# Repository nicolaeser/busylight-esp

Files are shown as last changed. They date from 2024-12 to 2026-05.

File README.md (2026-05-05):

# NOTICE: REPOSITORY IS NOW ARCHIVED
# CODE IS HOSTED @ http://code.igox.org/iGoX/busylight

# Table of Content

1. [What's this project?](#whats-this-project)
2. [Web UI](#web-ui)
3. [Stream Deck plug-in](#stream-deck-plug-in)
4. [BusyLight API](#busylight-api)
5. [MuteDeck integration](#mutedeck-integration)
6. [Electronic parts](#electronic-parts)
7. [Firmware installation](#firmware-installation)
8. [3D files - Enclosure](#3d-files---enclosure)
9. [Wiring / Soldering](#wiring--soldering)
10. [Tools & libs](#tools--libs)

# What's this project?

**Let people know if they can bother you with light signals!**

A cheap, simple to build, nice looking and portable DIY **Busy Light**.

It comes with a with a simplistic but neat **Web UI** and a simple (but hopefully convenient) **Rest API**.

| Controlled by Stream Deck with REST API | Light roll | 
|---|---|
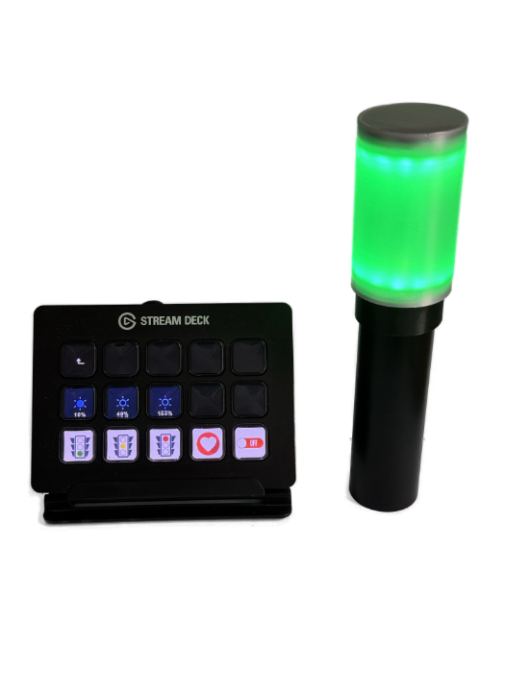
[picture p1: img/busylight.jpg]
busylight and stream deck
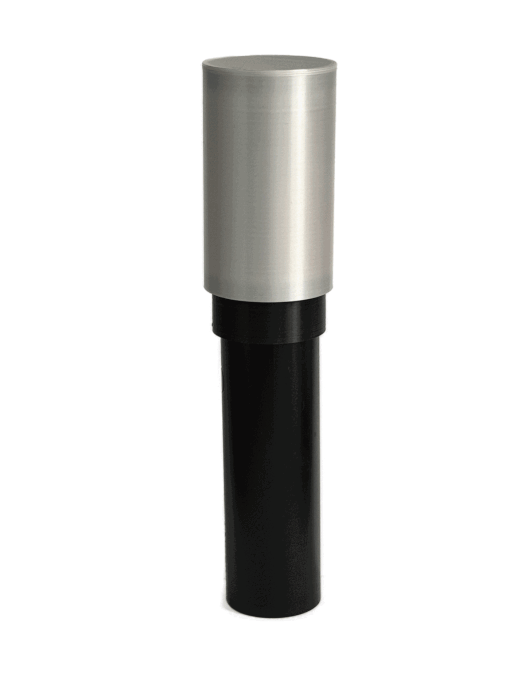
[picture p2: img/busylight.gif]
busylight roll
|  |   |

showoff video

# Web UI
A very simplistic but neat UI is available on port `80` (thanks @nicolaeser). \
Default hostname is `igox-busylight`.

You can try to reach the web UI @ [http://igox-busylight.local](http://igox-busylight.local). 

| What an neat UI ! :smile: |
|---------------------------|
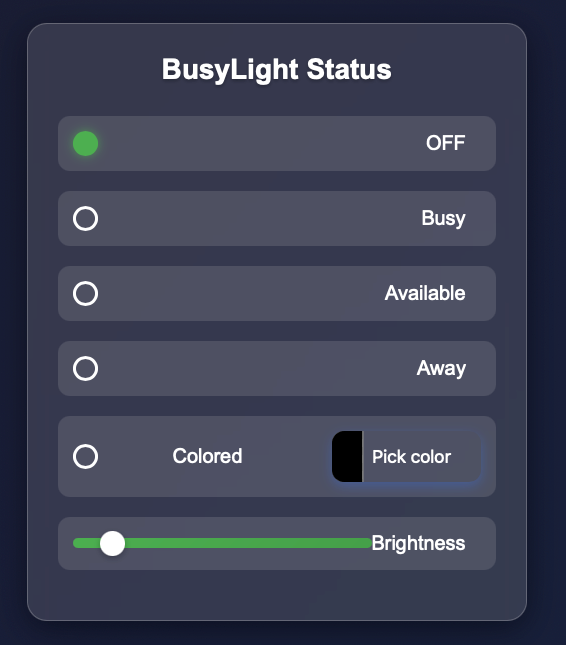
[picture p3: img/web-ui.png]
Web UI
|  |

# Stream Deck plug-in
You can download a Stream Deck plugin to control your BusyLight:

get it on marketplace Get iGoX BusyLight on Marketplace (https://marketplace.elgato.com/product/igox-busylight-7448a0be-6dd6-4711-ba0d-86c52b9075b9)

Or directly from [here](streamdeck-plugin/README.md).

# BusyLight API
## End points
| Path | Method | Parameter | Description |
|---|---|---|---|
| /api/color | POST | `color` JSON object | Set the BusyLight color according to the `color` object passed in the request body. Return a `status` object. |
| /api/color |  GET | n/a | Retreive the color currently displyed by the BusyLight. Return a `color` object. |
| /api/brightness | POST | `brightness` JSON object | Set the BusyLight brightness according to the `brightness` object passed in the request body. Return a `status` object. |
| /api/brightness | GET | n/a | Retreive the BusyLight brightness. Return a `brightness` object. |
| /api/status/on | POST / GET | n/a | Light up the BusyLight. White color. Return a `status` object. |
| /api/status/available | POST / GET | n/a | Set the BusyLight in `available` mode. Green color. Return a `status` object. |
| /api/status/away | POST / GET | n/a | Set the BusyLight in `away` mode. Yellow color. Return a `status` object. |
| /api/status/busy | POST / GET | n/a | Set the BusyLight in `busy` mode. Red color. Return a `status` object. |
| /api/status/off | POST / GET | n/a | Shutdown the BusyLight. Return a `status` object. |
| /api/status |  GET | n/a | Retreive the current BusyLight status. Return a `status` object. |
| /api/debug |  GET | n/a | Retreive the full BusyLight status. |

## JSON objects
### `color` object

```
{
  "r": 255,
  "g": 0,
  "b": 127,
  "brightness": 0.5
}
```
`r`: RED color | integer | [0 .. 255]\
`g`: GREEN color | integer | [0 .. 255]\
`b`: BLUE color | integer | [0 .. 255]\
`brightness`: LED brighness (optional)  | float | [0.0 .. 1.0]

### `brightness` object

```
{
  "brightness": 0.5
}
```
`brightness`: LED brighness | float | [0.0 .. 1.0]

### `status` object

```
{
  "status": "<STATUS>"
}
```

\<STATUS\> : `on` | `off` | `available` | `away` | `busy` | `colored`

# MuteDeck integration
The `POST api/mutedeck-webhook` endpoint aims to collect [MuteDeck](https://mutedeck.com/help/docs/notifications.html#enabling-the-webhook-integration) webhook callbacks.

It will automatically switch to the BusyLight in:
- busy mode (Red color) when entering a meeting with Mic `ON` **and** camera `ON`.
- away mode (Yellow color) when entering a meeting with Mic `OFF` **and** camera `ON`.
- away mode (Yellow color) if the mic is muted during a meeting.
- available mode (Green color) when exiting/closing a meeting.

| MuteDeck Configuration                            |
|---------------------------------------------------|
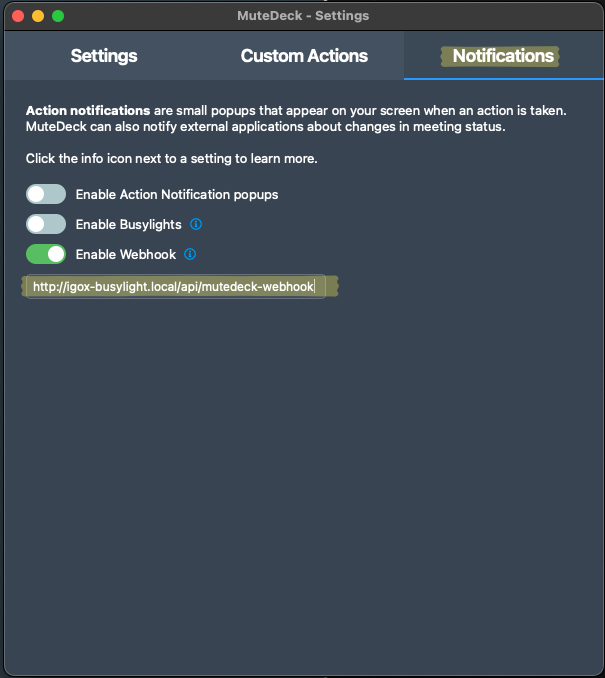
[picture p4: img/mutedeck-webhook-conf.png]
MuteDeck config
|  |

# Electronic parts
| Parts | Links (Amazon - not affiliated) |
|---|---|
| Micro-controler | [D1 ESP32 Mini NodeMCU](https://www.amazon.fr/dp/B0CDXB48DZ) - USB C version |
| Led rings (x2) | [AZDelivery 5 x LED Ring 5V RGB compatible avec WS2812B 12-Bit 38mm](https://www.amazon.fr/dp/B07V1GGKHV) |
| Battery | [Anker PowerCore 5000mAh](https://www.amazon.fr/dp/B01CU1EC6Y) |
| USB A to USB C adapter  | [USB A to USB C adapter](https://www.amazon.fr/dp/B0BYK917NM) |

# Firmware installation

**(1)** Flash your ESP32 with [Micropython](https://micropython.org/download/ESP32_GENERIC/).

**(2)** Install [microdot](https://microdot.readthedocs.io/en/latest/index.html) library on the ESP32. This can easily be done using [Thonny](https://thonny.org):

| Tools > Manage plug-ins | lib selection |
|---|---|
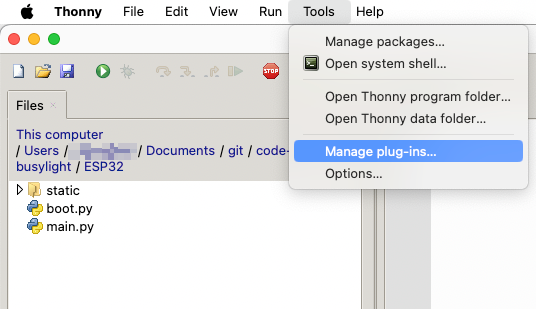
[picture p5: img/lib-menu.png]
lib-menu
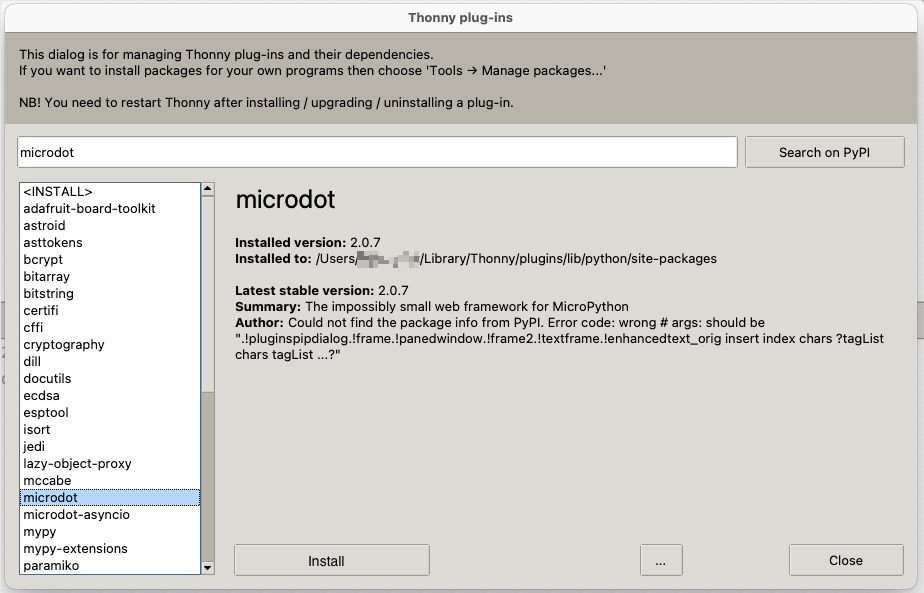
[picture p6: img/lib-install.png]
lib-install
|  |  |

**(3)** Edit the `WIFI Configuration` section in the [boot.py](ESP32/boot.py) file.

**(4)** Copy the content of [ESP32](ESP32/) folder with the modified `boot.py` file to the root of your ESP32 file system. Again, can easily be done using [Thonny](https://thonny.org):

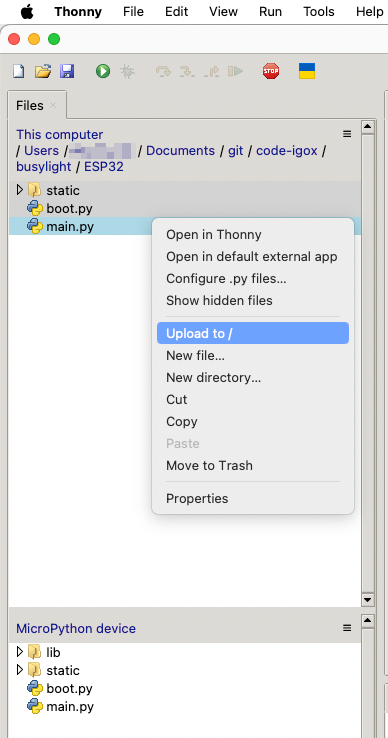
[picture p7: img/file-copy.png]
file-copy


**Done!**

# 3D files - Enclosure

All the required 3D files (STLs and f3d project) to 3D print the enclosure are available in the [3D-files-to-print](3D-files-to-print/) folder.

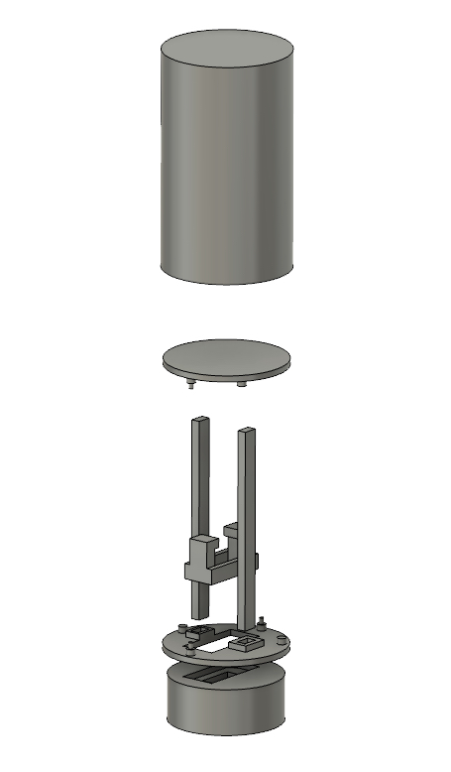
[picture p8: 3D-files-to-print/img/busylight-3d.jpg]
3D files


# Wiring / Soldering

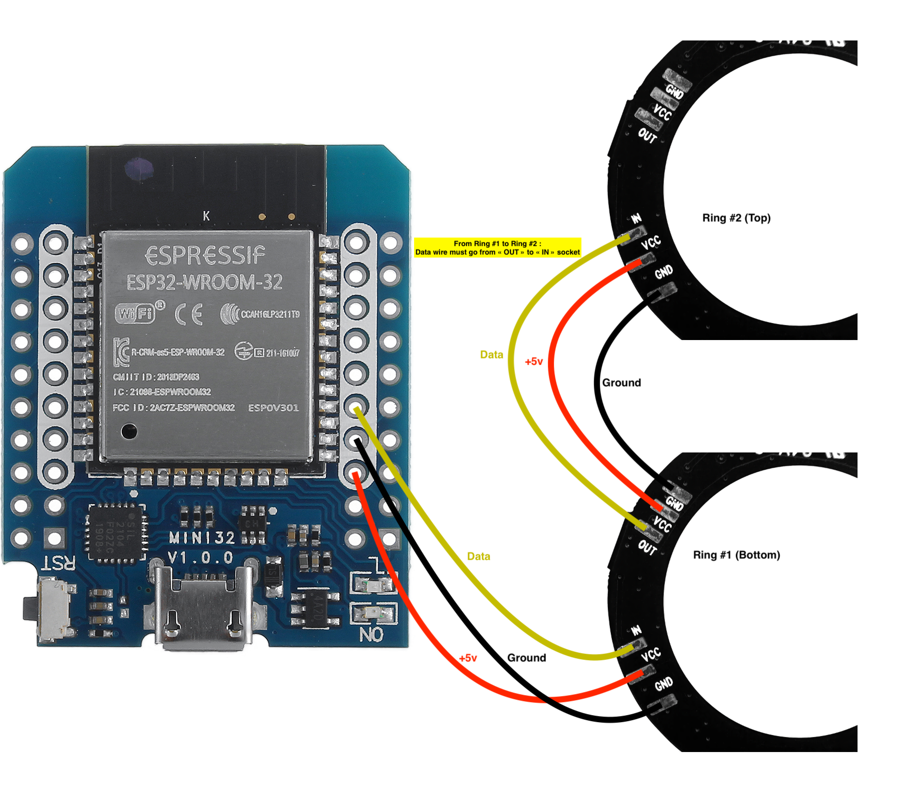
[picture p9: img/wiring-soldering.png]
wiring-soldering


You can see a final assembly image [here](3D-files-to-print/README.md).

# Tools & libs

## Thonny
https://thonny.org

## Micropython
https://micropython.org

## Microdot
https://microdot.readthedocs.io/en/latest/index.html

## JSColor
https://jscolor.com

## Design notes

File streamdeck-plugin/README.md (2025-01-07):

# BusyLight Stream Deck plugin - Release notes

## Version 0.3.1.0 (2024-01-06)

### Download

[org.igox.busylight.v0.3.1.0.streamDeckPlugin](download/org.igox.busylight.v0.3.1.0.streamDeckPlugin)

### Features

- None added

### Enhancements

- Add colored button for "Set color" action.
- Add colored button for "Set brightness" action.
- Update plugin and plugin category icons

### Fixes

- None.

### Bugs & known limitations

- None known at publication time.

### Screenshot

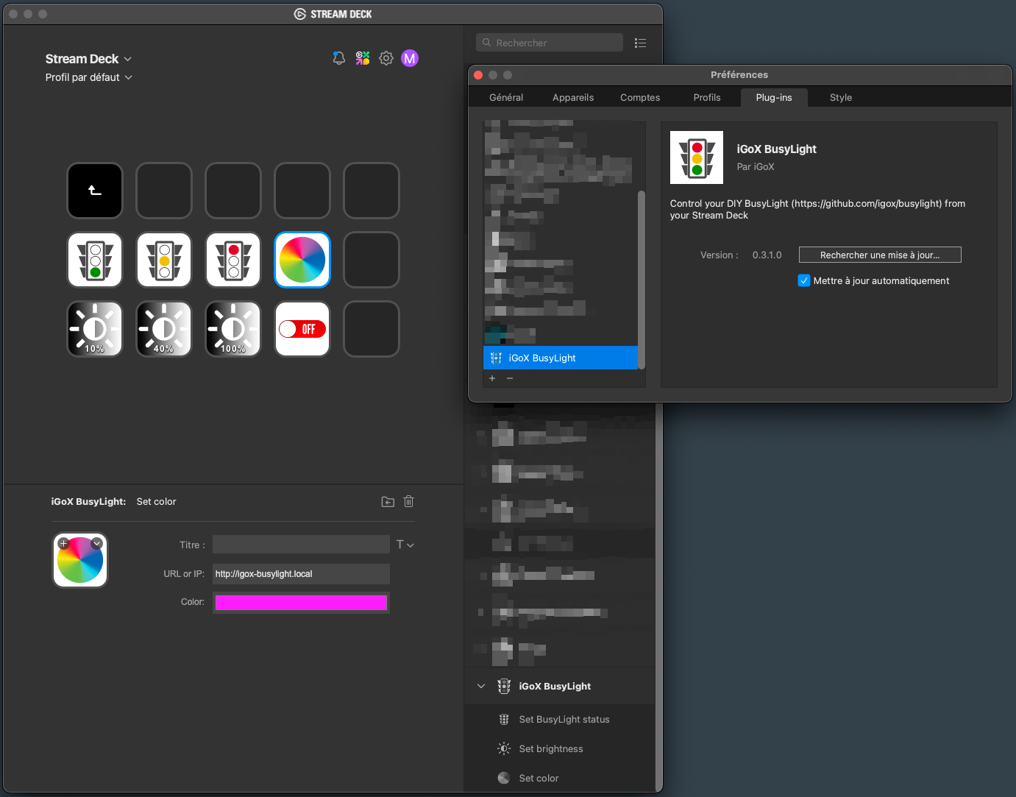
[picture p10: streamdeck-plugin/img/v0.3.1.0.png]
v0.3.1.0 screenshot


## Version 0.3.0.0 (2024-01-06)

### Download

[org.igox.busylight.v0.3.0.0.streamDeckPlugin](download/org.igox.busylight.v0.3.0.0.streamDeckPlugin)

### Features

- None added

### Enhancements

- Rework icons to comply with plugin guidelines for Elgato Marketplace
- Combine the 3 "status" actions into a single action and having the status be selected with a dropdown

### Fixes

- None.

### Bugs & known limitations

- None known at publication time.

### Screenshot

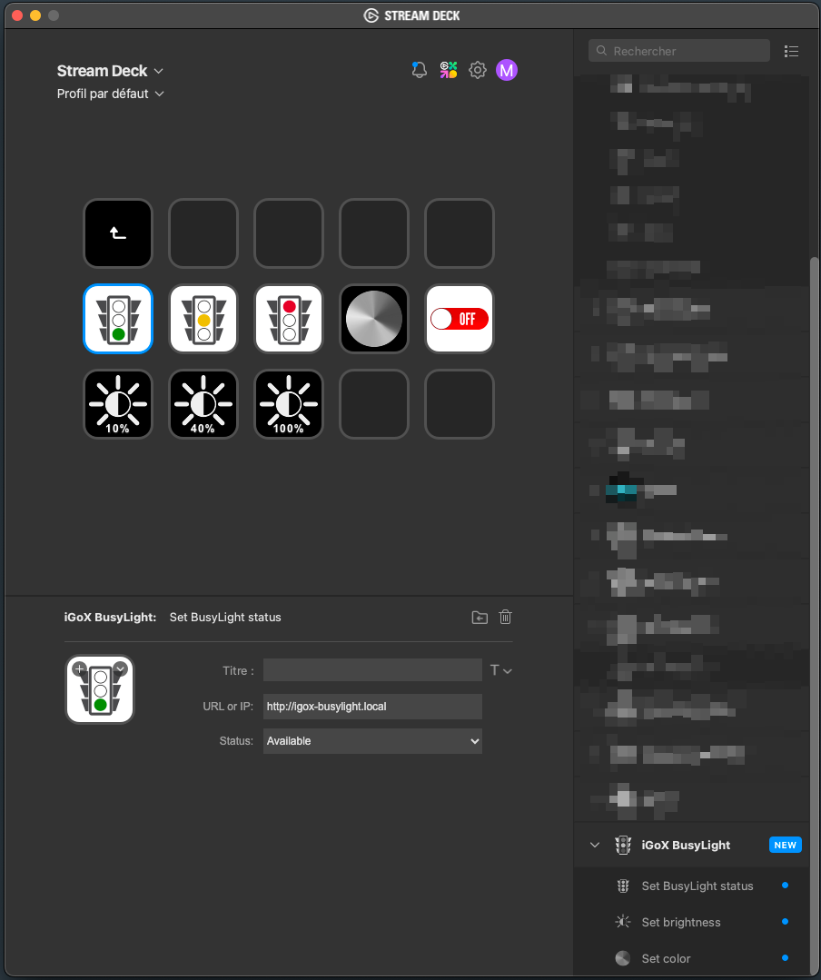
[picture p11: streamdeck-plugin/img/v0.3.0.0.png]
v0.3.0.0 screenshot


## Version 0.2.0.0 (2024-12-28)

### Download

[org.igox.busylight.v0.2.0.0.streamDeckPlugin](download/org.igox.busylight.v0.2.0.0.streamDeckPlugin)

### Features

- Add the capability to set the color diplayed by BusyLigh LEDs.

### Fixes

- None.

### Bugs & known limitations

- None known at publication time.

### Screenshot

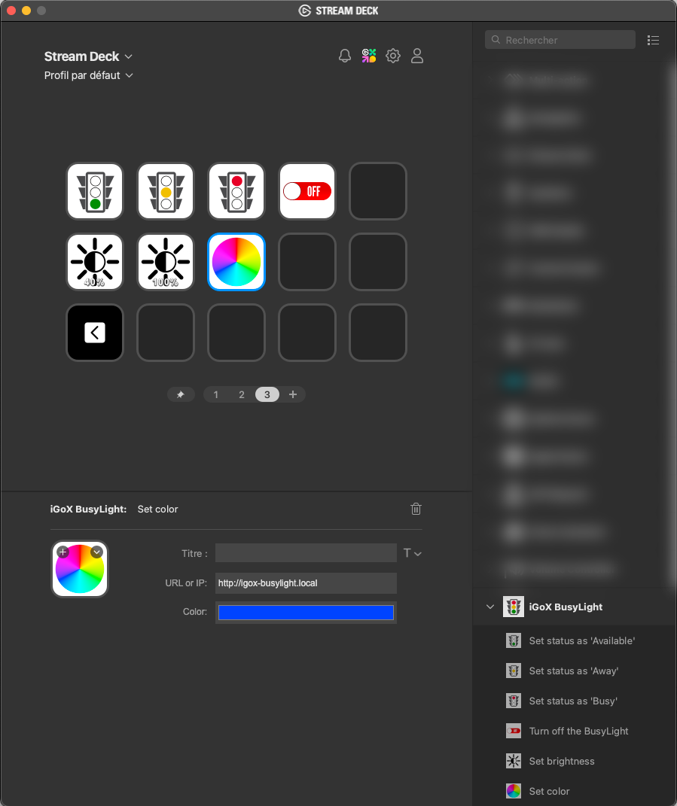
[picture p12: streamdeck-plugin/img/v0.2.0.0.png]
v0.2.0.0 screenshot


## Version 0.1.0.0 (2024-12-28)

### Download

[org.igox.busylight.v0.1.0.0.streamDeckPlugin](download/org.igox.busylight.v0.1.0.0.streamDeckPlugin)

### Features

- Quick action buttons to set the BusyLight status (Available: green, Away: yellow, Busy: red).
- Quick action button to turn off the BusyLight.
- Button to set the BusyLight brightness.

### Fixes

- None: initial version of the plugin.

### Bugs & known limitations

- None known at publication time.

### Screenshot

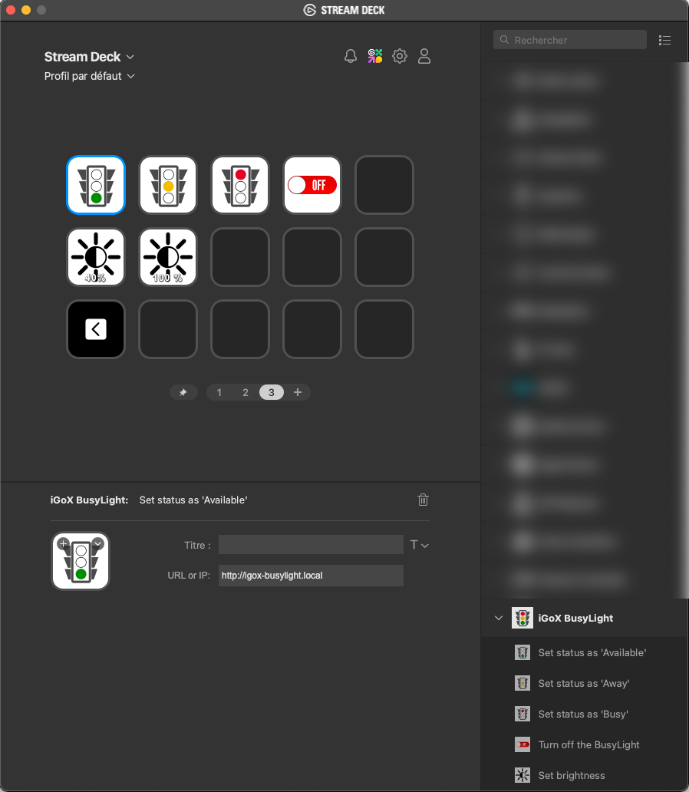
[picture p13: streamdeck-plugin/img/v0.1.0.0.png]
v0.1.0.0 screenshot


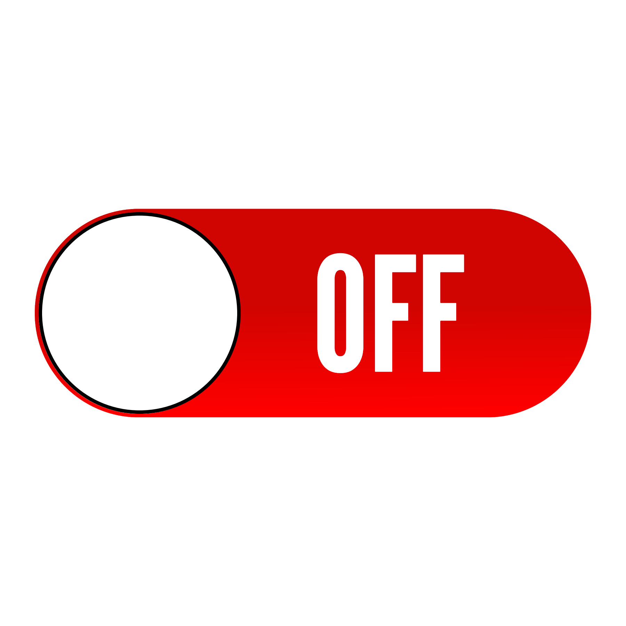
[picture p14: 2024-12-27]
streamdeck-plugin/busylight/org.igox.busylight.sdPlugin/imgs/actions/buttons/off/off@2x.png

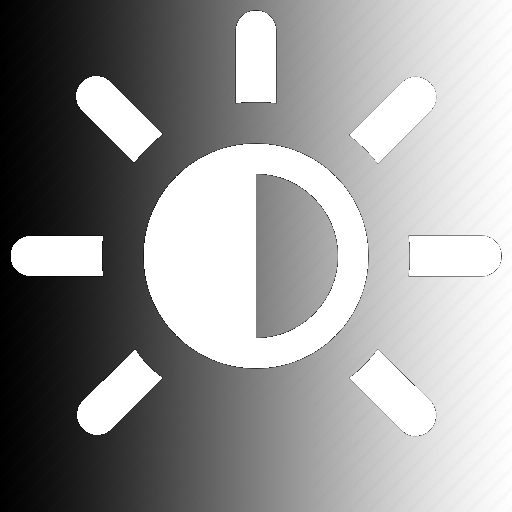
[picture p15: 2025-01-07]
streamdeck-plugin/busylight/org.igox.busylight.sdPlugin/imgs/actions/buttons/brigthness/brigthness@2x.png

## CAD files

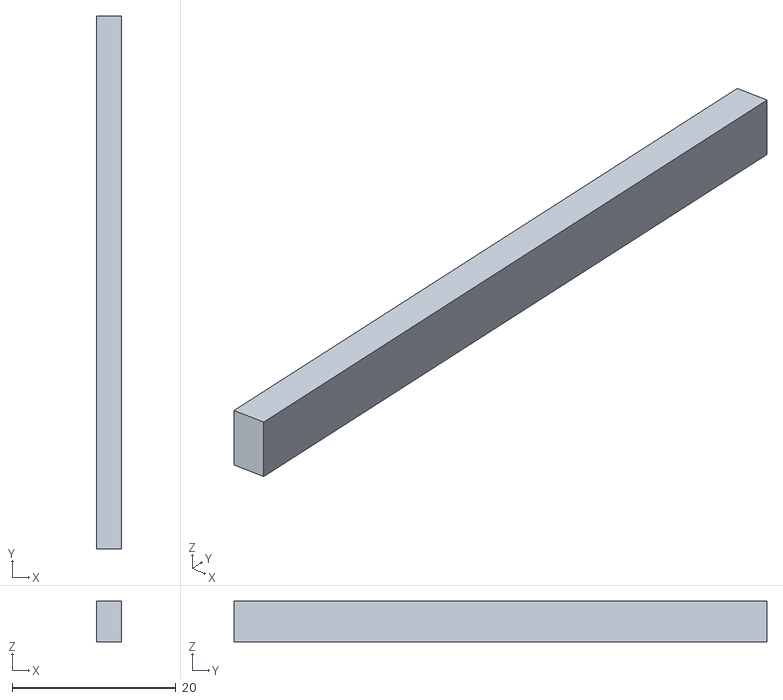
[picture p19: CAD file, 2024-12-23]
3D-files-to-print/Raiser.stl
3.00 x 65.0 x 5.00

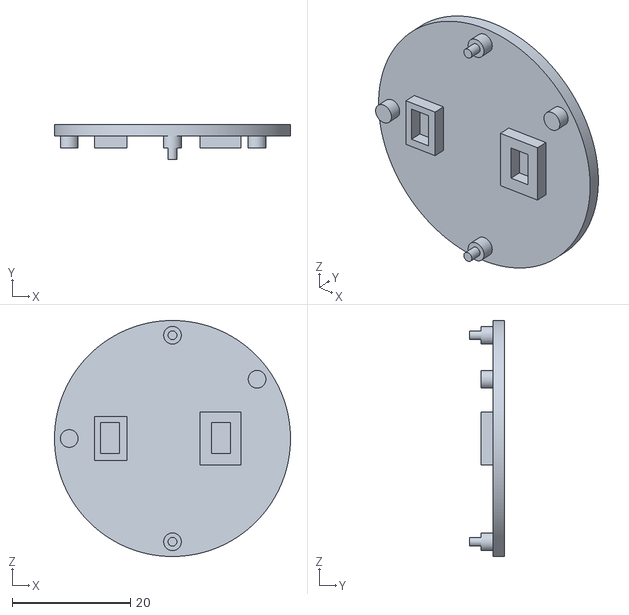
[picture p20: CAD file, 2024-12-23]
3D-files-to-print/LED support top.stl
40.0 x 6.00 x 40.0

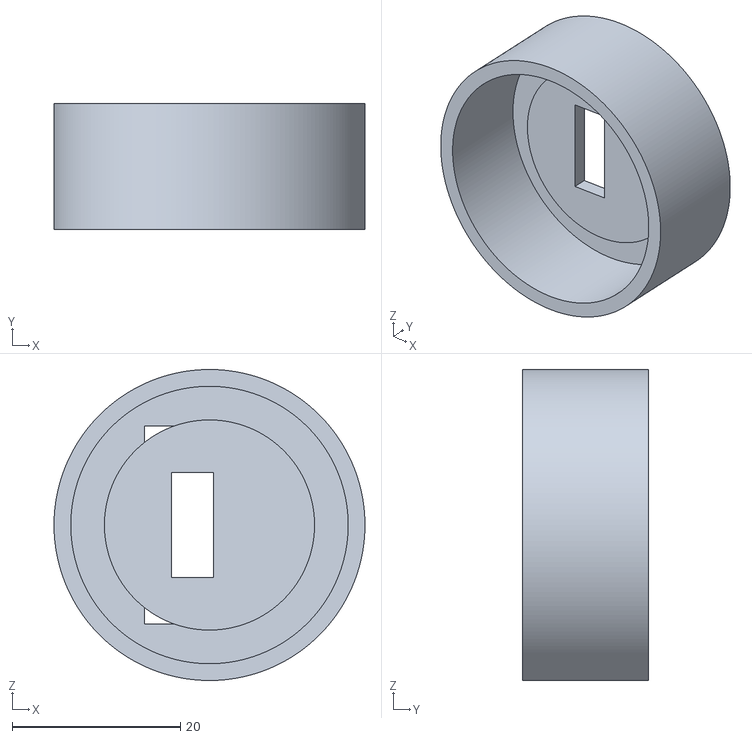
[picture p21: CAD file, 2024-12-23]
3D-files-to-print/USB plate.stl
37.0 x 15.0 x 37.0

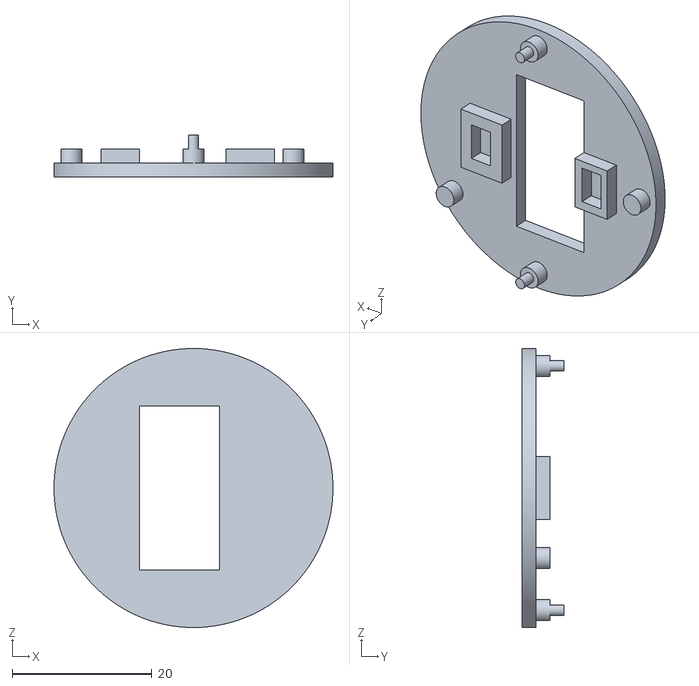
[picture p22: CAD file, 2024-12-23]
3D-files-to-print/LED support bottom.stl
40.0 x 6.00 x 40.0

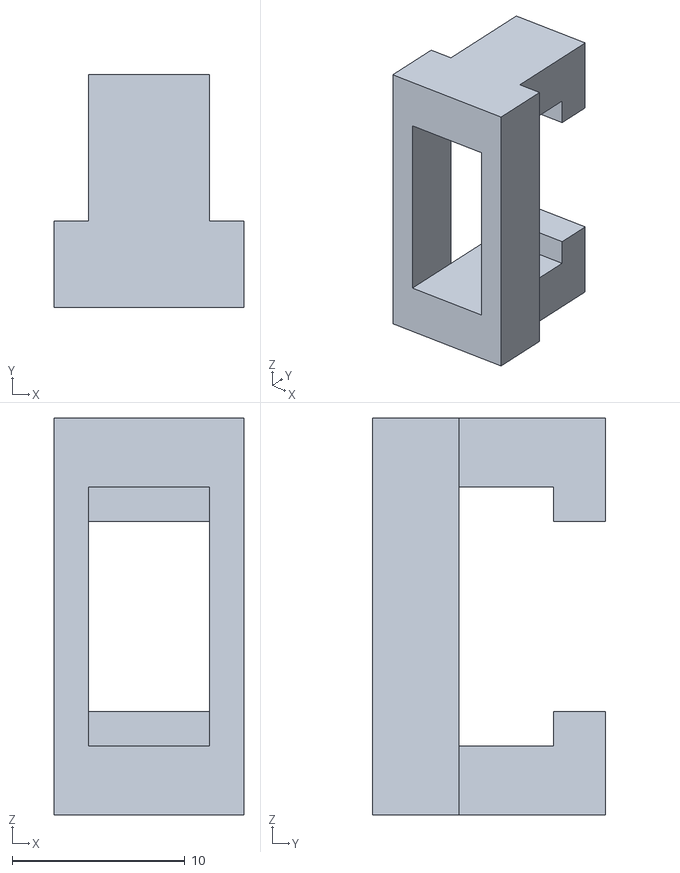
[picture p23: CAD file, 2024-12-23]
3D-files-to-print/USB holder.stl
11.0 x 13.5 x 23.0

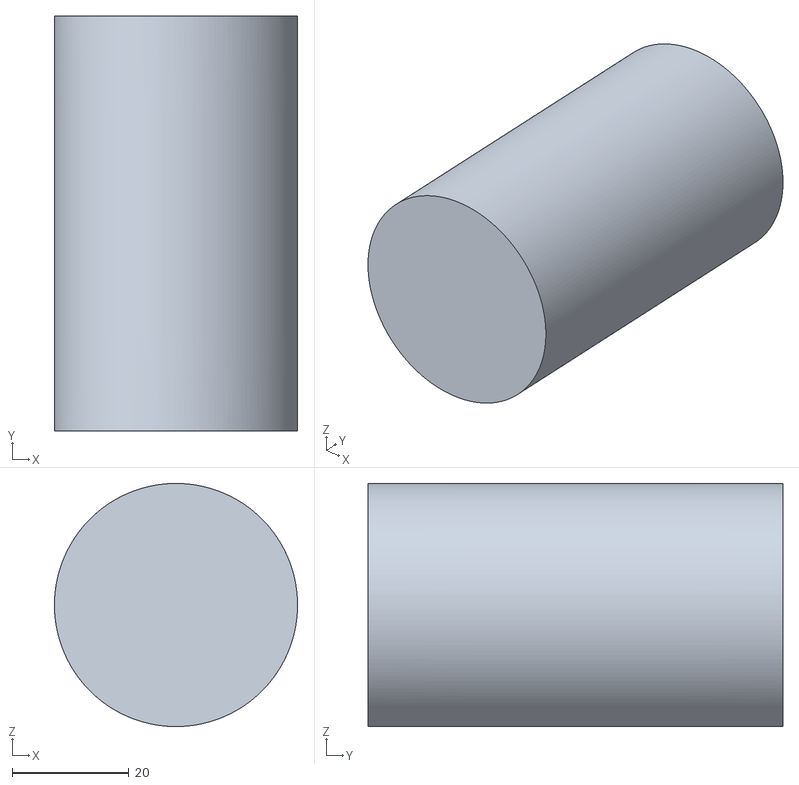
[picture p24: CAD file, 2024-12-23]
3D-files-to-print/LED cover.stl
41.6 x 71.0 x 41.6

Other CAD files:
3D-files-to-print/Busylight v2.f3d

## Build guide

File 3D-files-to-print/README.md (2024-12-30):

Loctite glue and hot glue gun are you friends :smile:

All files can be printed in PLA. \
To have a nice light diffusion, I printed the `LED cover.stl` file in [_vase mode_](https://all3dp.com/2/cura-vase-mode-all-you-need-to-know/).

3D model

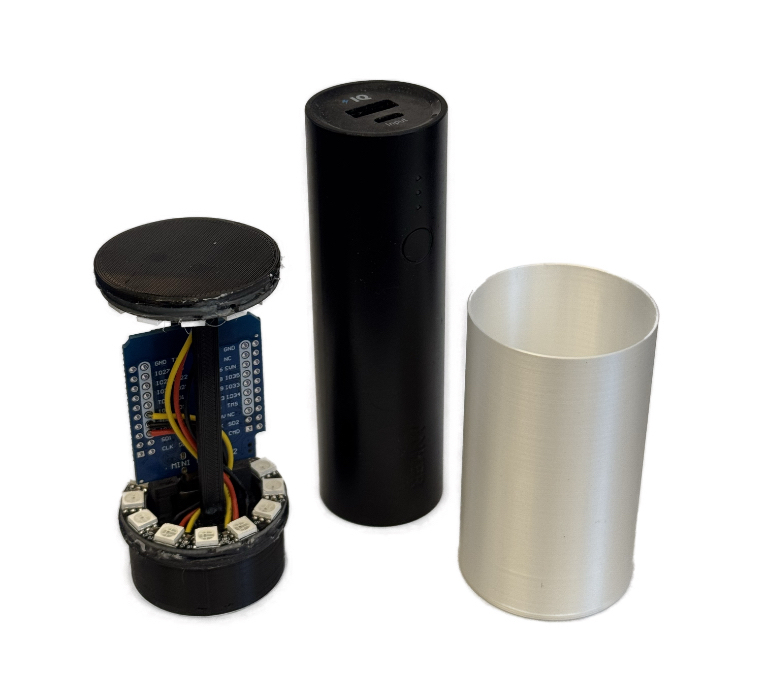
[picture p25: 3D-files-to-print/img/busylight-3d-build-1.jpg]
Build


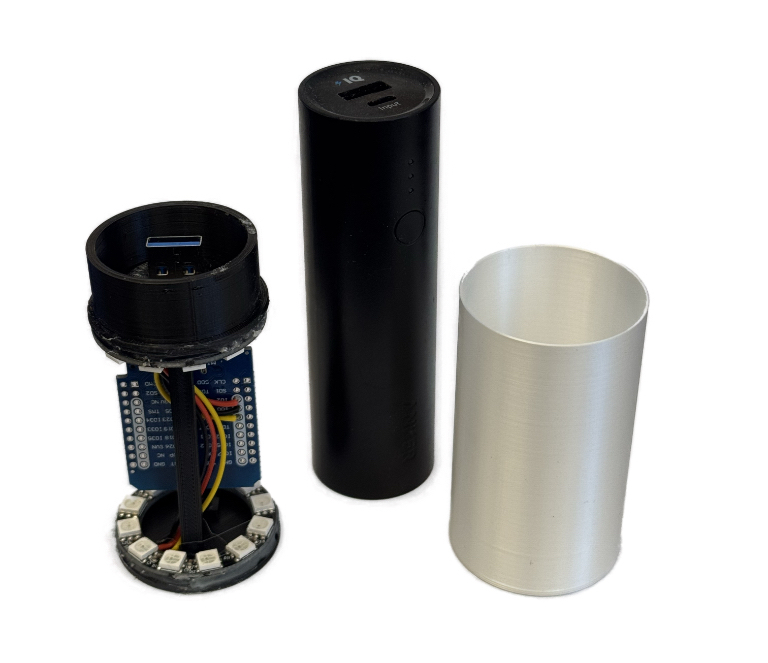
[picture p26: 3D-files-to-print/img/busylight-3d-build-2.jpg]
Build


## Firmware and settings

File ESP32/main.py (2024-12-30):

from microdot import Microdot, send_file
import machine, sys, neopixel, time

app = Microdot()

# Difine NeoPixel object
nbPixels = 12*2
pinPixelStrip = 16   # ESP32 D1 Mini
neoPixelStrip = neopixel.NeoPixel(machine.Pin(pinPixelStrip), nbPixels)

# Define status colors
statusColors = {
    'BUSY': (255,0,0),          # red
    'AVAILABLE': (0,255,0),     # green
    'AWAY': (246,190,0),        # cyan
    'OFF': (0, 0, 0),           # off
    'ON': (255, 255, 255)       # white
    }

# Store BusyLight default global status
blColor = statusColors.get('OFF')
blStatus = 'off'
blPreviousStatus='off'
blBrightness = 0.1 # Adjust the brightness (0.0 - 1.0)
    
def __setColor(color):
    r, g , b = color
    r = int(r * blBrightness)
    g = int(g * blBrightness)
    b = int(b * blBrightness)
    return (r, g, b)

def __setBusyLightColor(color, brightness):
    global blBrightness
    blBrightness = brightness
    global blColor
    blColor = color
    neoPixelStrip.fill(__setColor(color))
    neoPixelStrip.write()
    
    global blStatus
    blStatus = 'colored'

def __setBusyLightStatus(status):
    status = status.upper()
    color = statusColors.get(status)
    __setBusyLightColor(color, blBrightness)
    
    global blStatus
    blStatus = status.lower()

# Microdot APP routes

@app.get('/static/<path:path>')
async def staticRoutes(request, path):
    if '..' in path:
        # directory traversal is not allowed
        return {'error': '4040 Not found'}, 404
    return send_file('static/' + path)

@app.get('/')
async def getIndex(request):
    return send_file('static/index.html')

@app.get('/api/brightness')
async def getBrightness(request):
    return {'brightness': blBrightness}

@app.post('/api/brightness')
async def setBrightness(request):
    brightness = request.json.get("brightness")
    
    if brightness is None:
        return {'error': 'missing brightness parameter'}, 400
    
    if type(brightness) is float \
       or type(brightness) is int:
        if brightness < 0 or brightness > 1:
            return {'error': 'brigthness out of bound (0.0 - 1.0)'}, 400
    else:
        return {'error': 'wrong brigthness type (float)'}, 400
    
    # Save blStatus
    global blStatus
    status = blStatus
    
    # Apply new brightness to current color
    color = blColor
    __setBusyLightColor(color, brightness)
    
    # Restore global status
    blStatus = status
    
    global blBrightness
    blBrightness = brightness
    
    return {'brightness': blBrightness}
    

@app.post('/api/color')
async def setColor(request):
    
    r = request.json.get("r")
    g = request.json.get("g")
    b = request.json.get("b")

    if bool(r is None or g is None or b is None):
        return {'error': 'missing color'}, 400
    else:
        if type(r) is int \
           and type(g) is int \
           and type(b) is int:
            color = (r, g, b)
        else:
            return {'error': 'wrong color type (int)'}, 400
        
    if (r < 0 or r > 255) \
       or (g < 0 or g > 255) \
       or (b < 0 or b > 255):
        return {'error': 'color out of bound (0 - 255)'}, 400
    
    brightness = request.json.get("brightness")
    
    if not brightness is None:
        if type(brightness) is float \
           or type(brightness) is int:
            if brightness < 0 or brightness > 1:
                return {'error': 'brightness out of bound (0.0 - 1.0)'}, 400
        else:
            return {'error': 'wrong brightness type (float)'}, 400
        __setBusyLightColor(color, brightness)
    
    __setBusyLightColor(color, blBrightness)

    return {'status': blStatus}

@app.route('/api/status/<status>', methods=['GET', 'POST'])
async def setStatus(request, status):
    lStatus = status.lower()
    if lStatus == 'on':
        __setBusyLightStatus('ON')
    elif lStatus == 'off':
        __setBusyLightStatus('OFF')
    elif lStatus == 'available':
        __setBusyLightStatus('AVAILABLE')
    elif lStatus == 'away':
        __setBusyLightStatus('AWAY')
    elif lStatus == 'busy':
        __setBusyLightStatus('BUSY')
    else:
        return {'error': 'unknown /api/status/' + lStatus + ' route'}, 404
    
    return {'status': blStatus}

@app.get('/api/color')
async def getColor(request):
    r, g, b = neoPixelStrip.__getitem__(0)
    return {'color': {'r': r, 'g': g, 'b': b}}

@app.get('/api/status')
async def getStatus(request):
    return {'status': blStatus}

@app.get('/api/debug')
async def getDebugInfo(request):
    r, g, b = blColor
    dr, dg, db = neoPixelStrip.__getitem__(0)
    return {'status': blStatus, 'brightness': blBrightness, 'color': {'r': r, 'g': g, 'b': b}, 'dimColor': {'r': dr, 'g': dg, 'b': db}}

@app.post('/api/mutedeck-webhook')
async def mutedeckWebhook(request):
    
    if request.json.get('control') != 'system':
        if request.json.get('call') == 'active':
            if request.json.get('mute') == 'active':
                isMuted = True
            else:
                isMuted = False
                
            if request.json.get('video') == 'active':
                isVideoOn = True
            else: 
                isVideoOn = False
                
            if isMuted: 
                __setBusyLightStatus('away')
            else:  
                __setBusyLightStatus('busy')
    else:
        __setBusyLightStatus('available')

    return {'status': blStatus}


@app.post('/shutdown')
async def shutdown(request):
    request.app.shutdown()
    return 'The server is shutting down...'

# Startup effect
def startUpSeq():
    print('Start seq begins')
    __setBusyLightStatus('OFF')
    time.sleep_ms(100)
    __setBusyLightStatus('BUSY')
    time.sleep_ms(200)
    __setBusyLightStatus('AWAY')
    time.sleep_ms(300)
    __setBusyLightStatus('AVAILABLE')
    time.sleep_ms(500)
    __setBusyLightStatus('OFF')
    print('Start seq is ended')
    __setBusyLightColor(statusColors.get('OFF'), 0.1)
    
startUpSeq()
        
# Start API webserver
if __name__ == '__main__':
    app.run(port=80, debug=True)

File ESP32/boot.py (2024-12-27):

# This file is executed on every boot (including wake-boot from deepsleep)
# It is executed before main.py
import os, machine
import network
import gc

gc.collect()


# --- WIFI Configuration ---
SSID = '<YOUR WIFI SSID>'               # Set the WIFI network SSID
PASSWORD = '<YOUR WIFI PASSWORD>'       # Set the WIFI network password
network.country('<YOUR COUNTRY CODE>')  # Set the country code for the WIFI (ISO 3166-1 Alpha-2 country code)
network.hostname('igox-busylight')     # Hostname that will identify this device on the network
# --------------------------

# Function to connect to the WIFI
def boot_wifi_connect():
    wlan = network.WLAN(network.STA_IF)
    if not wlan.isconnected():
        print('connecting to network...')
        wlan.active(True)
        wlan.connect(SSID, PASSWORD)
        while not wlan.isconnected():
            pass
    ip, mask, gateway, dns = wlan.ifconfig()
    
    # Print the network configuration
    print('\nNetwork config:')
    print('- IP address: ' + ip)
    print('- Network mask: ' + mask)
    print('- Network gateway: ' + gateway)
    print('- DNS server: ' + dns + '\n')

# Connect to the WIFI when booting
boot_wifi_connect()

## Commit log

2024-12-23 3D print section - Add images of build (#6)
2024-12-27 Add capability to set LED color (#16)
2024-12-30 Add wiring / soldering schema (#21)
